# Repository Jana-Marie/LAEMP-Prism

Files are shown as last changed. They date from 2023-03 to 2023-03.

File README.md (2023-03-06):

# LAEMP-Prism

The LÄMP-Prism is an aesthetically pleasing and colorful effect lamp that can be used in your home. It can be controlled using Zigbee (e.g., Philips Hue) and has RGBY + WW/CW LEDs, providing a wide dynamic range and fantastic color representation. The lamp can be soldered together at home or assembled by JLCPCB.

An inbuilt slow fade-animation creates plenty colored dots around the room, one can choose from three different animations by quickly bringing red from 0% to 100% and back three times. LAEMP will switch from static light, to slow-fading dots to being an RGB-beacon. Its most pleasing mode is the slow-fading animation. It is fast enough to raise the rooms texture, slow enough to not be irritating and just perfect for comfy nights.

The project consists of nine PCBs that are cleverly interlocked with pinheaders and capacitors. The Prism-like shape, combined with its 291 LEDs, projects a slightly changing dotted pattern into its environment.

<table>
  <tbody>
    <tr>
      <td>
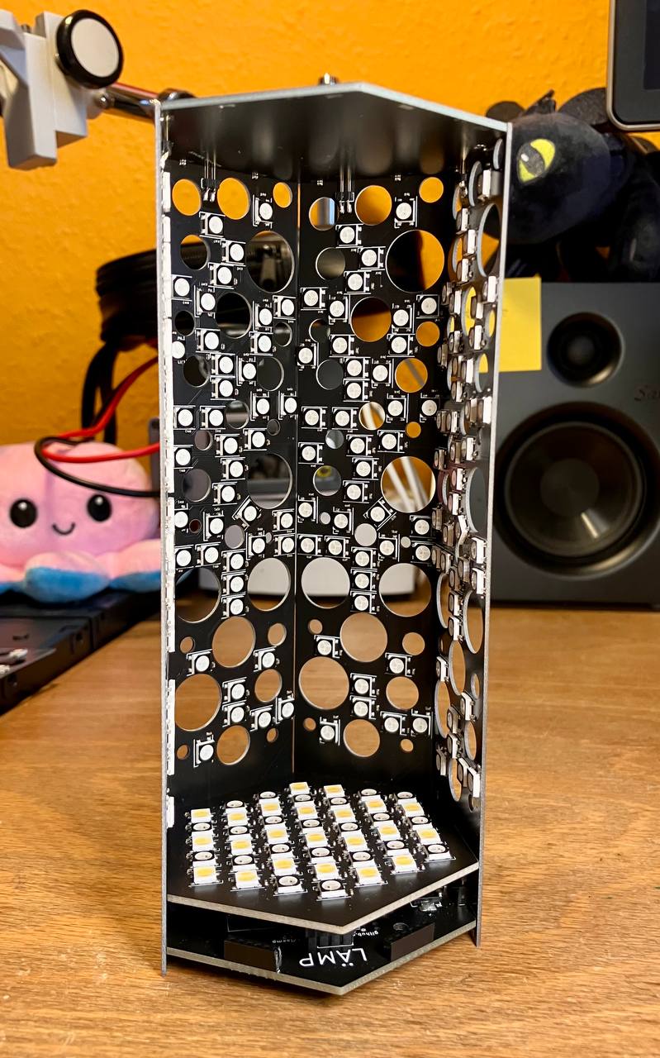
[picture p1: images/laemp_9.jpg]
        
      </td>
      <td>
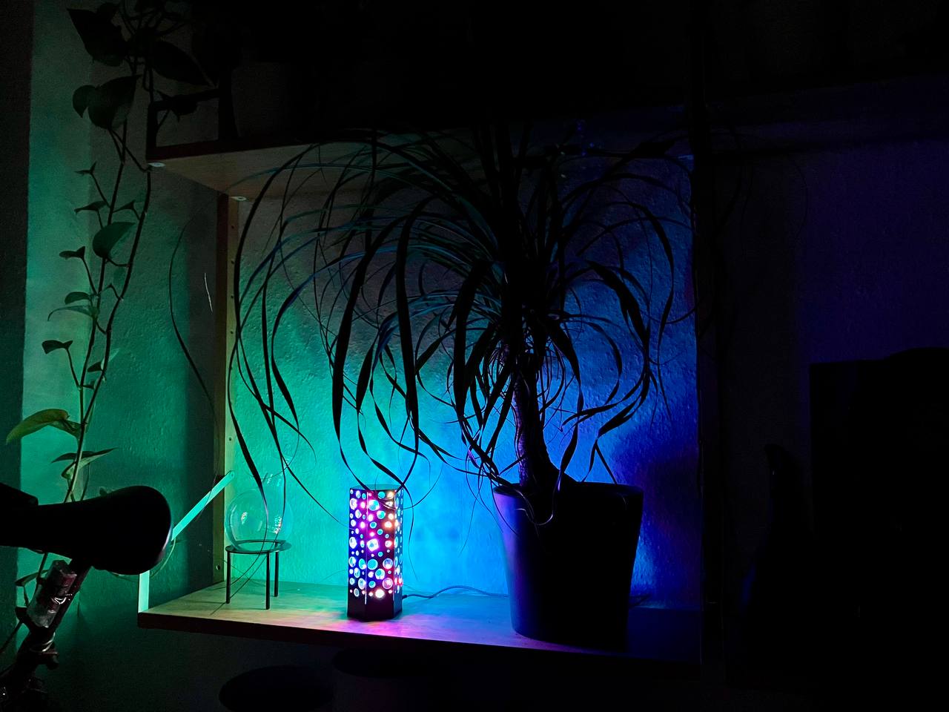
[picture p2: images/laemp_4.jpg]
        
      </td>
    </tr>
  </tbody>
</table>

This project is an attempt to add some colored lights and interesting patterns to ones home. I hope you enjoy it! :3

<table>
  <tbody>
    <tr>
      <td>
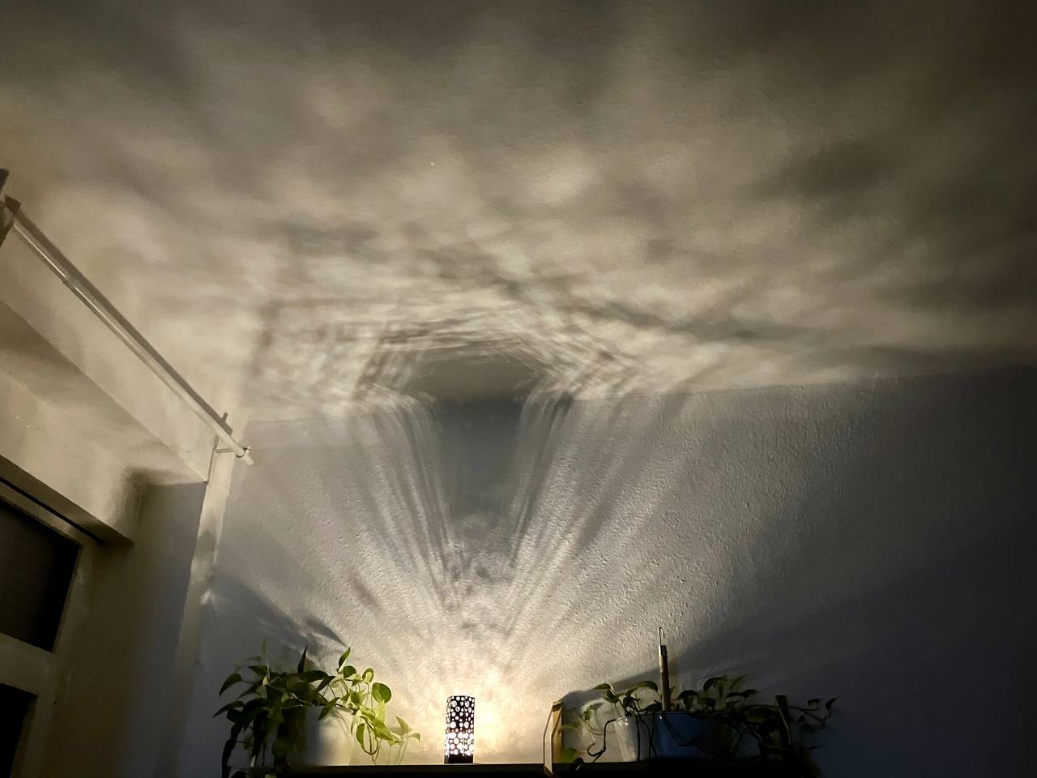
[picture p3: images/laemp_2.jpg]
        
      </td>
      <td>
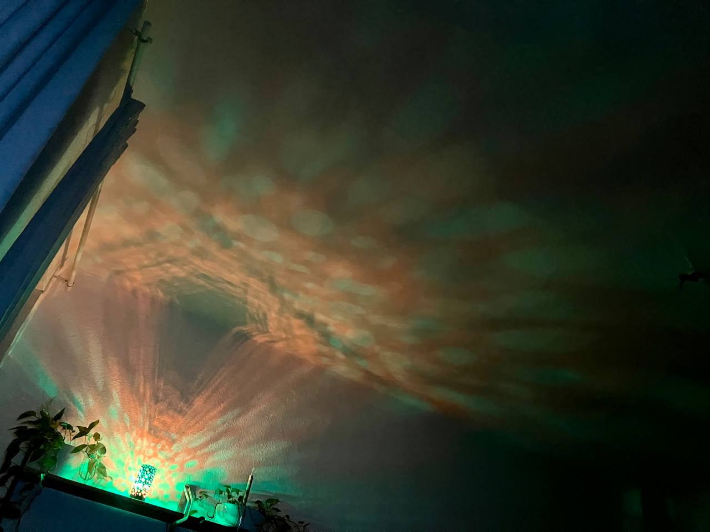
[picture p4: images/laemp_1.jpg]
        
      </td>
    </tr>
  </tbody>
</table>

### V2

Please note that the E75-2G4M20S module is End of Life and is hard to obtain. I'm working on a V2.0 with STM32WB (see [MiniBee](https://github.com/Jana-Marie/MiniBee)). The Hex-Base-Board is henceforth subject to be updated, all other boards shouldnt change.

### Sister project

LAEMP-Prism is a sister project to [LAEMP-Panel](https://github.com/Jana-Marie/LAEMP-Panel)

## Concept

The overall concept was developed in OpenSCAD and a pseudo-random pattern of circles was choosen for the walls. If one wants to put effort into this project, different walls can be used. The standard base-to-wall-interface also allows for much different and custom walls. E.g. hexagonal holes, shorter or taller walls, bended walls, ...

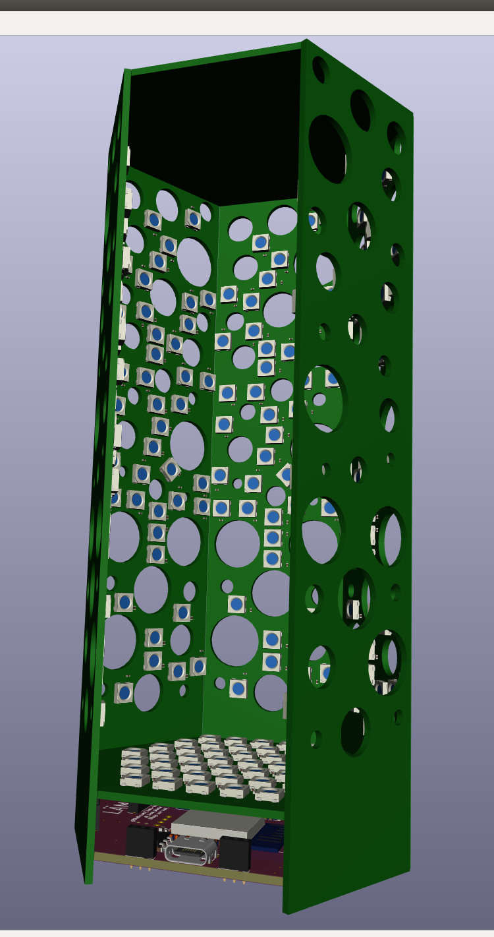
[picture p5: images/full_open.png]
full open


## Build

This build is definitely time-consuming, as each LAEMP Prism features 291 LEDs, and therefore requires at least 291 100nF capacitors. Additionally, the wall PCBs are rather thin and long, making reflow difficult and assembly time-consuming.

Once all eight boards are assembled (the top board has no components ^⁻^), they can be interlocked with one another. To do this, begin by plugging the LED-Base-Board into the Base-Board, and then carefully plugging wall after wall into the baseboard. Try to put the Top-Board onto the build after assembling five boards. The board with the Type-C cutout should not be the last board to assemble. Finally, try to plug in the last board. This step can be quite tricky and may require a few attempts. Once all boards are assembled, align all walls with each other and place the whole board onto the 3D printed base.

You will need the following set of baords for a build:

 - 1 x Base-Board
 - 1 x Base-LED-Board
 - 1 x Top-Board
 - 5 x Wall-Board
 - 1 x USB-Wall-Board

<table>
  <tbody>
    <tr>
      <td>
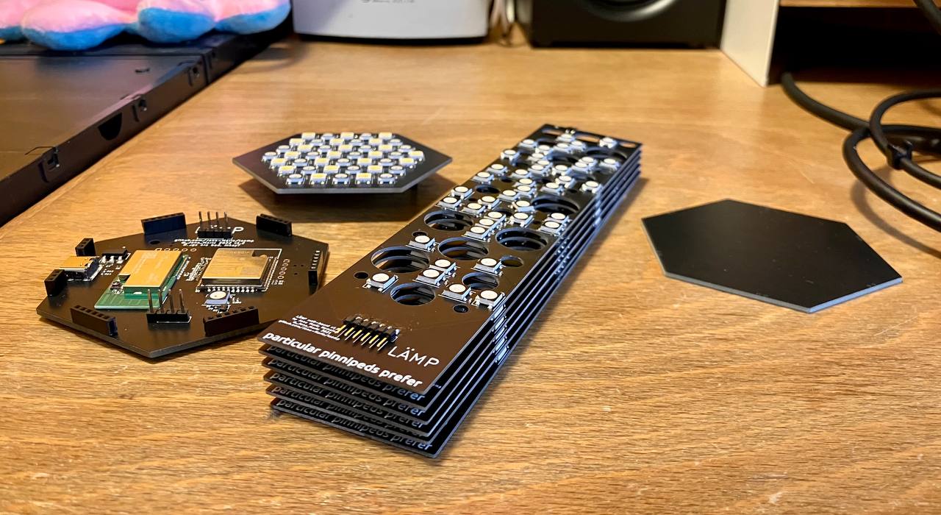
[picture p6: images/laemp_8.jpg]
        
      </td>
      <td>
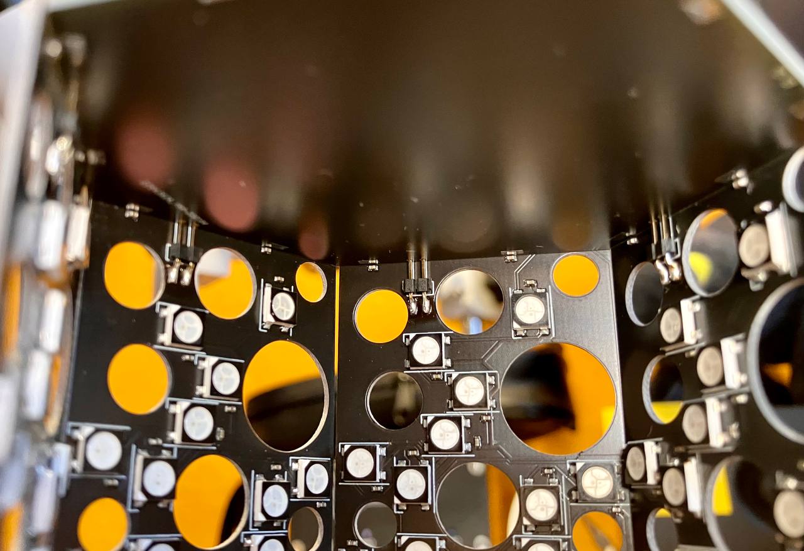
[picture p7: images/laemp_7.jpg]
        
      </td>
    </tr>
    <tr>
      <td>
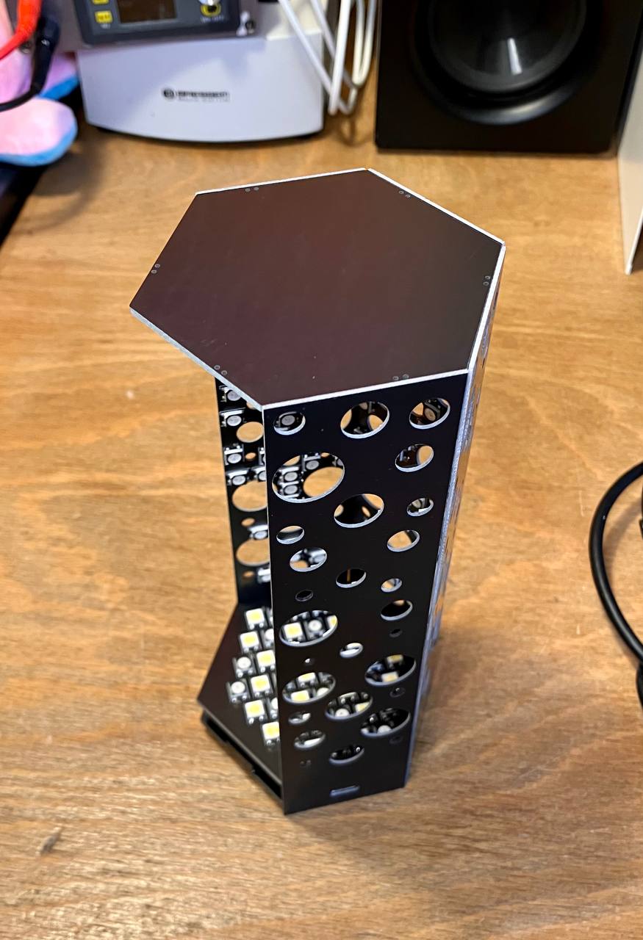
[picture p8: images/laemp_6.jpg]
        
      </td>
      <td>
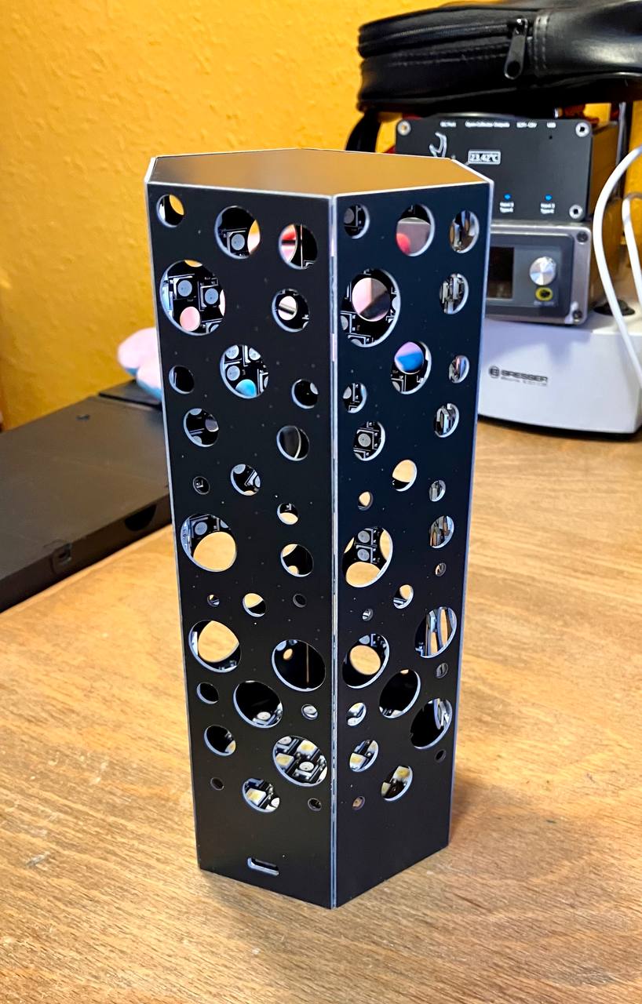
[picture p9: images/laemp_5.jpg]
        
      </td>
    </tr>
  </tbody>
</table>

## Firmware

There are two firmwares to be flashed, one for the ESP32 and one for the E75-2G4M20S.

### ESP32

This is a simple Arduino project and can be flashed via Arduino (initially built on Arduino 1.8.19).

### E75

Please refer to the awesome works of [PeeVeeOne](https://peeveeone.com/zll-tldr/) to flash `Light_ColorLight_JN5168_RGB` onto the E75-2G4M20S module.

## Todo

 - [ ] Bug: Animation selector sucks, it gets stuck on states, needs fix.
 - [ ] Bug: Color wheel is off
 - [ ] Update to baseboard v2

## Folder Structure

```
 - 3D/               3D-Printable base, Concept
 - design/           assets, renders
 - images/           images for README
 - laemp_base/       base board hosting the MCU(s)
 - laemp_led_board/  LED base board, plugs directly ontop of the base board
 - laemp_top/        top board, has no electrical functionality, just mechanical
 - laemp_wall/       wall board, hosting 41 leds each
 - laemp_wall_usb/   same wall board, but with USB cutout
 - firmware/
   - leamp_prism/    ESP32 FW
   - zigbee/         E75 FW
```

## License

Copyright Jana Marie Hemsing 2023.
This source describes Open Hardware and is licensed under the CERN-
OHL-S v2.

You may redistribute and modify this source and make products using it
under the terms of the CERN-OHL-S v2
([LICENSE](/LICENSE)).

This source is distributed WITHOUT ANY EXPRESS OR IMPLIED
WARRANTY, INCLUDING OF MERCHANTABILITY, SATISFACTORY
QUALITY AND FITNESS FOR A PARTICULAR PURPOSE. Please see
the CERN-OHL-S v2 for applicable conditions.

Source location: https://github.com/Jana-Marie/LAEMP-Prism/
As per CERN-OHL-S v2 section 4, should You produce hardware based
on this source, You must where practicable maintain the Source Location
visible on the external case of LAEMP-Prism or other products you make using
this source

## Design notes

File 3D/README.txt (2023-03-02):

# Structure

```
 ./laemp.scad
   Project file
 ./laemp_base.scad
   3D printable project base
 ./laemp_base.stl
   Print me!
 ./laemp_wall_1.dxf
   KiCAD outline file
```

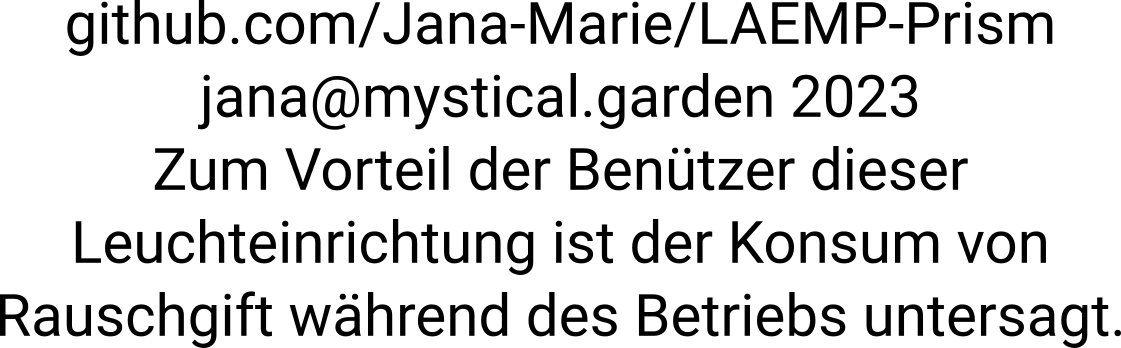
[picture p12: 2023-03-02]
design/bottom_text.png

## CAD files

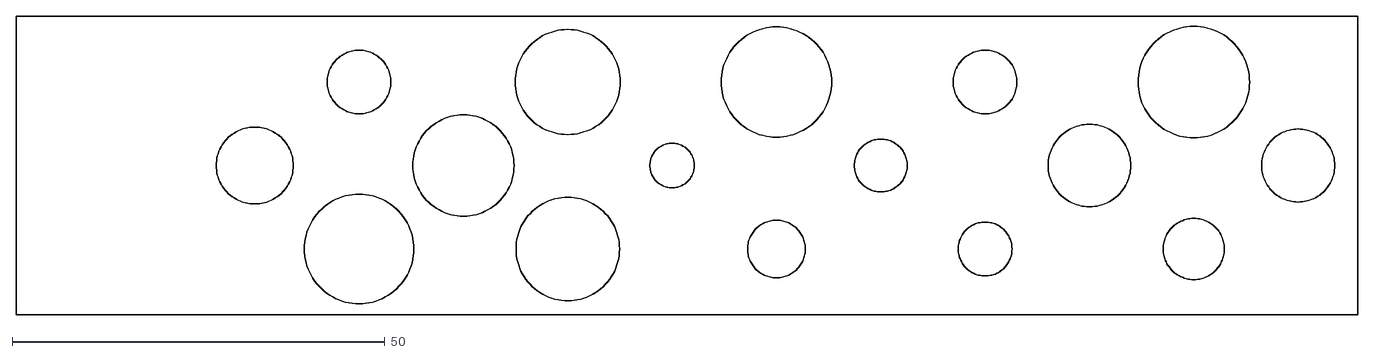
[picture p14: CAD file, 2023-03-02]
3D/laemp_wall_1.dxf
180.0 x 40.0

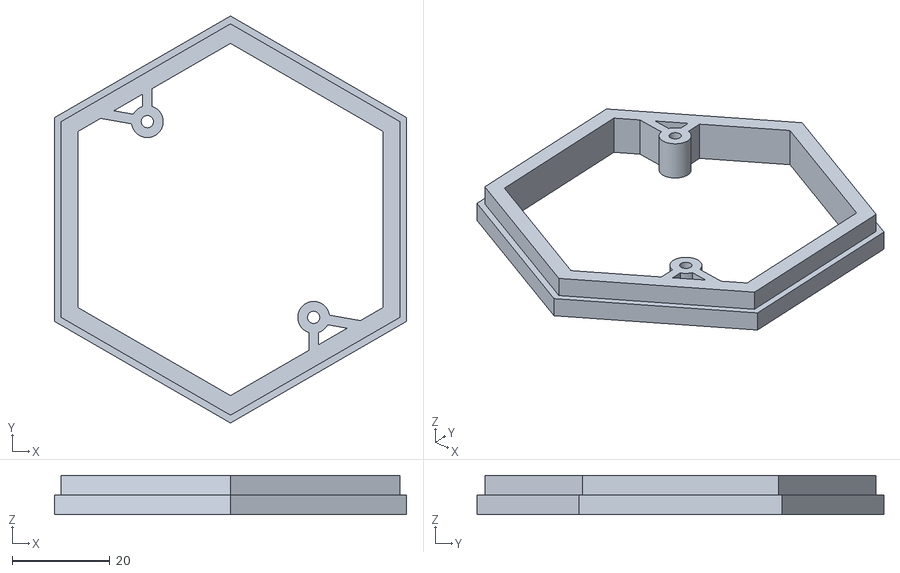
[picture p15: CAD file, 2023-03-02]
3D/laemp_base.stl
72.1 x 83.2 x 8.00

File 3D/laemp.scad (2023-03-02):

$fn = 100;
sidelenth=40;
height=180;

#color("darkgrey")
for(r=[0:60:300])rotate([0,0,r])translate([sidelenth*sqrt(3)/2+0.5,0,0])rotate([0,-90,0])wall_1(height,sidelenth);

//wall_1(height,sidelenth);

color("grey")translate([0,0,height])hexagon(sidelenth,true);

color("grey")translate([0,0,10])hexagon(sidelenth,true);

color("grey")translate([0,0,20])hexagon(sidelenth,true);

module wall_1(h=100,l=40,t=0.8){
    difference(){
        union(){
            translate([h/2,0,0])square([h,l],center=true);
        } union(){
            _xoff=32;
            _xdiff=28;
            for(i = [0:1:10]){
                for(k = [-1:1:1]){
                    _d = rands(3,15,1)[0];
                    //ssecho(_d,k%2==0 ? _xoff+(i*_xdiff):_xoff+((i*_xdiff)+(_xdiff/2)),(k*_xdiff/2.5));
                    translate([k%2==0 ? _xoff+(i*_xdiff):_xoff+((i*_xdiff)+(_xdiff/2)),(k*_xdiff/2.5),0])
                        
                        circle(d=_d);
                }
            }
        }
    }
}

module hexagon(s, center=false){
    l = sqrt(3) * s;
    tr = center ? [0, 0, 0] : [s, l / 2, 0];
    translate(tr)for(r =[-60,0,60])rotate([0,0,r])square([l,s],center=true);
}

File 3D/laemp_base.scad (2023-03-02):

$fn=100;

color([0, 49/255, 83/255])laemp_base(4, 4, false);

module laemp_base(h=10, h_lower=5, thread=false){
    union(){
        // upper hexagon
        difference(){
            rotate([0,0,90])hexagon(40,h);
            translate([0,0,-0.5])rotate([0,0,90])hexagon(36,h+1);
        }
        // lower hexagon
        translate([0,0, -h_lower])
        difference(){
            rotate([0,0,90])hexagon(40+1.6,h_lower);
            translate([0,0,-0.5])rotate([0,0,90])hexagon(36,h_lower+1);
        }
        // screwholes
        translate([-17,20,-h_lower])mounting_holes(2.5,h+h_lower,2);
        translate([17,-20,-h_lower])mounting_holes(2.5,h+h_lower,2);
        // bridges
        translate([-17,20,h/2-h_lower/2]){
            rotate([0,0,90])translate([3+2,0,0])cube([6,2,h+h_lower],center=true);
            rotate([0,0,170])translate([5+2,0,0])cube([10,2,h+h_lower],center=true);
        }
        translate([17,-20,h/2-h_lower/2]){
            rotate([0,0,-90])translate([3+2,0,0])cube([6,2,h+h_lower],center=true);
            rotate([0,0,-10])translate([5+2,0,0])cube([10,2,h+h_lower],center=true);
        }
    }
}

module thread(do=10,di=9,s=1.9,h=10,res=5){
    ssize=360/res;
    for(i=[1:res:360/s*h]){
        rotate([0,0,i])translate([(do-di)/2,0,s*i/360-0.01])cylinder(h=s/ssize+0.02,d=di);
    }
}

module mounting_holes(sDia=3,h=1,wall=2){
    difference(){
        cylinder(d=wall*2+sDia,h=h);
        translate([0,0,-0.5])cylinder(d=sDia,h=h+1);
    }
}

module hexagon(x = 10, h = 1){
    cylinder(d=x*2, h=h, $fn=6);
}

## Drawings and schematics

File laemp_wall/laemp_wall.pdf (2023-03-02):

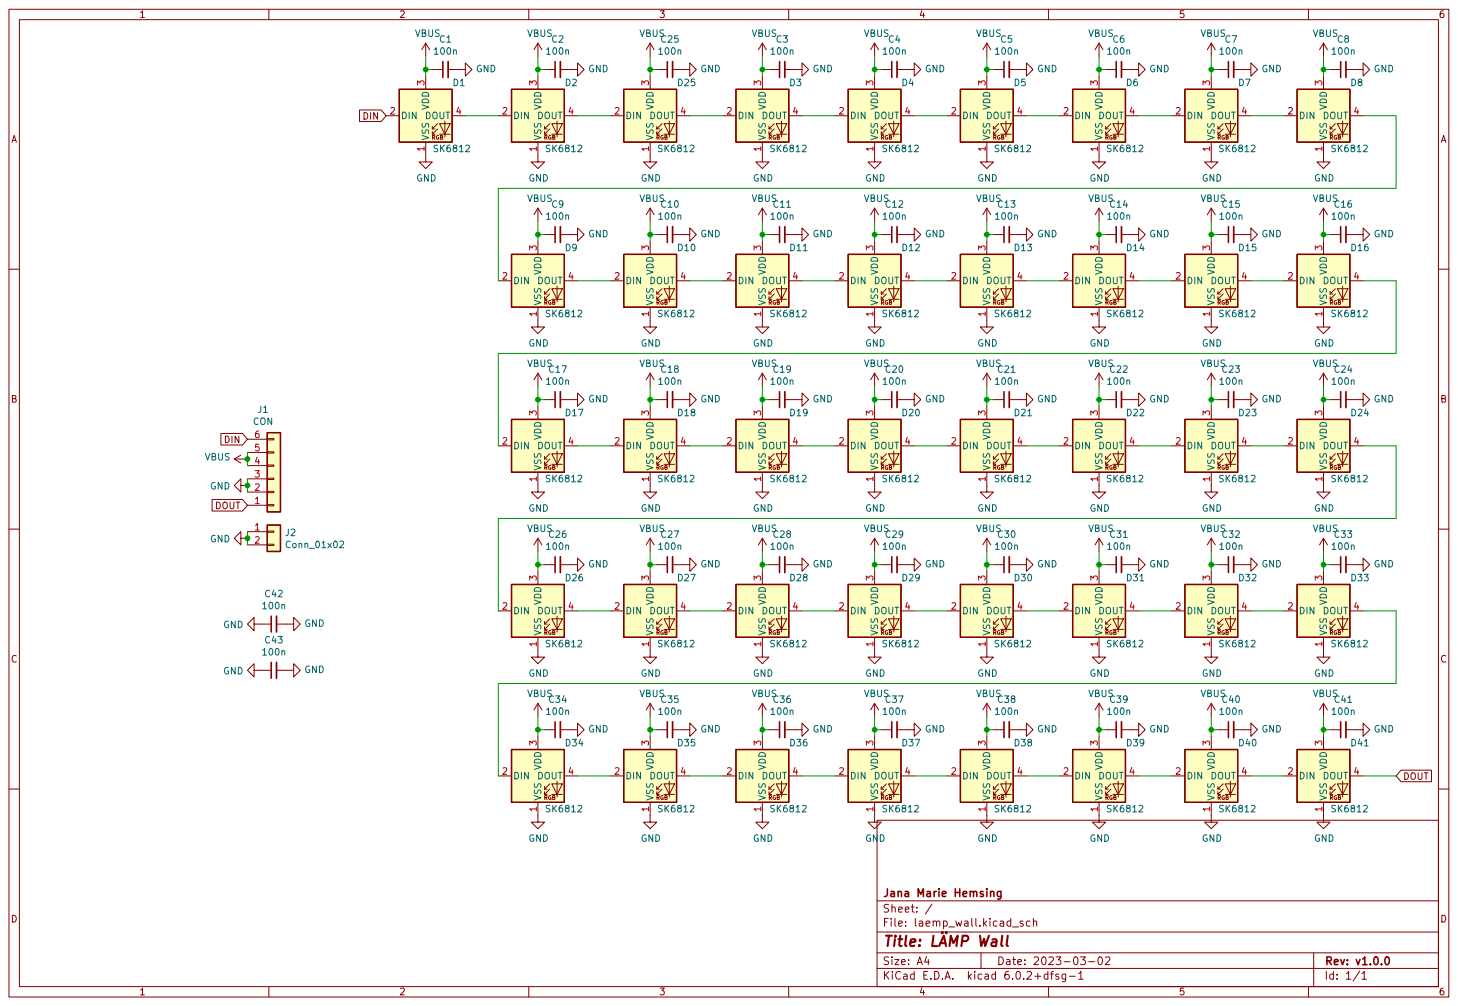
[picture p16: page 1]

3 DOUT 4D6 SK6812 VSS RGB 1 DIN 2 VDD

3 DOUT 4D23 SK6812 VSS RGB 1 DIN 2 VDD

3 DOUT 4D10 SK6812 VSS RGB 1 DIN 2 VDD

3 DOUT 4D11 SK6812 GNDVSS RGB 1 DIN 2 VDD

3 DOUT 4D13 SK6812 GND VSS RGB 1 DIN 2 VDD

3 DOUT 4D15 SK6812 GND GNDVSS RGB 1 DIN 2 VDD

3 DOUT 4D24 SK6812 VSS RGB 1 DIN 2 VDD

3 DOUT 4D40 SK6812 GND GNDVSS RGB 1 DIN 2 VDD

3 DOUT 4D20 SK6812 GND VSS RGB 1 DIN 2 VDD

3 DOUT 4D33 SK6812 GND GND VSS RGB 1 DIN 2 VDD

3 DOUT 4D31 SK6812 VSS RGB 1 DIN 2 VDD

3 DOUT 4D30 SK6812 VSS RGB 1 DIN 2 VDD

3 DOUT 4D37 SK6812 GND GNDVSS RGB 1 DIN 2 VDD

File: laemp_wall.kicad_sch Sheet: / Jana Marie Hemsing GND

3 DOUT 4D38 SK6812 VSS RGB 1 DIN 2 VDD

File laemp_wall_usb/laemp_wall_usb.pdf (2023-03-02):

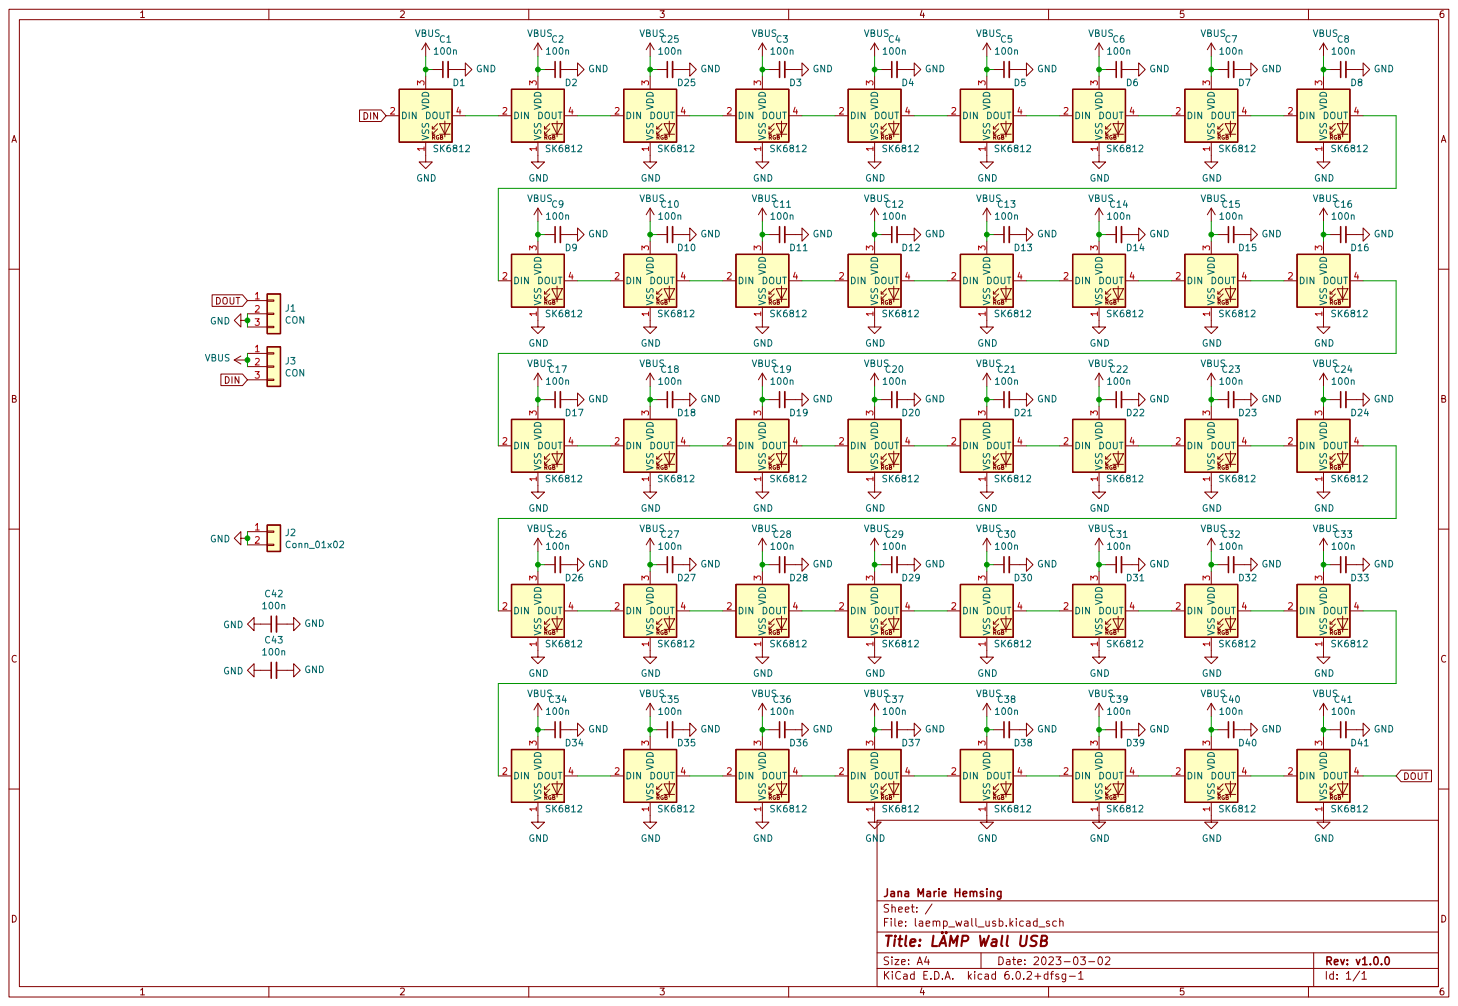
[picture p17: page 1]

3 DOUT 4D2 SK6812 VBUS GND GND

3 DOUT 4D8 SK6812 GND GND GND

3 DOUT 4D6 SK6812 VSS RGB 1 DIN 2 VDD

3 DOUT 4D20 SK6812 GND GND VSS RGB 1 DIN 2 VDD

3 DOUT 4D14 SK6812 GND GND GND GND VSS RGB 1 DIN 2 VDD

3 DOUT 4D12 SK6812 VSS RGB 1 DIN 2 VDD

3 DOUT 4D11 SK6812 VSS RGB 1 DIN 2 VDD

3 DOUT 4D10 SK6812 VSS RGB 1 DIN 2 VDD

3 DOUT 4D13 SK6812 VSS RGB 1 DIN 2 VDD

3 DOUT 4D23 SK6812 VSS RGB 1 DIN 2 VDD

3 DOUT 4D26 SK6812 GND GND VSS RGB 1 DIN 2 VDD

3 DOUT 4D29 SK6812 GNDVSS RGB 1 DIN 2 VDD

3 DOUT 4D27 SK6812 GND VSS RGB 1 DIN 2 VDD

3 DOUT 4D31 SK6812 GNDVSS RGB 1 DIN 2 VDD

3 DOUT 4D37 SK6812 VSS RGB 1 DIN 2 VDD

3 DOUT 4D41 SK6812 GND VSS RGB 1 DIN 2 VDD

3 DOUT 4D34 SK6812 GND GNDVSS RGB 1 DIN 2 VDD

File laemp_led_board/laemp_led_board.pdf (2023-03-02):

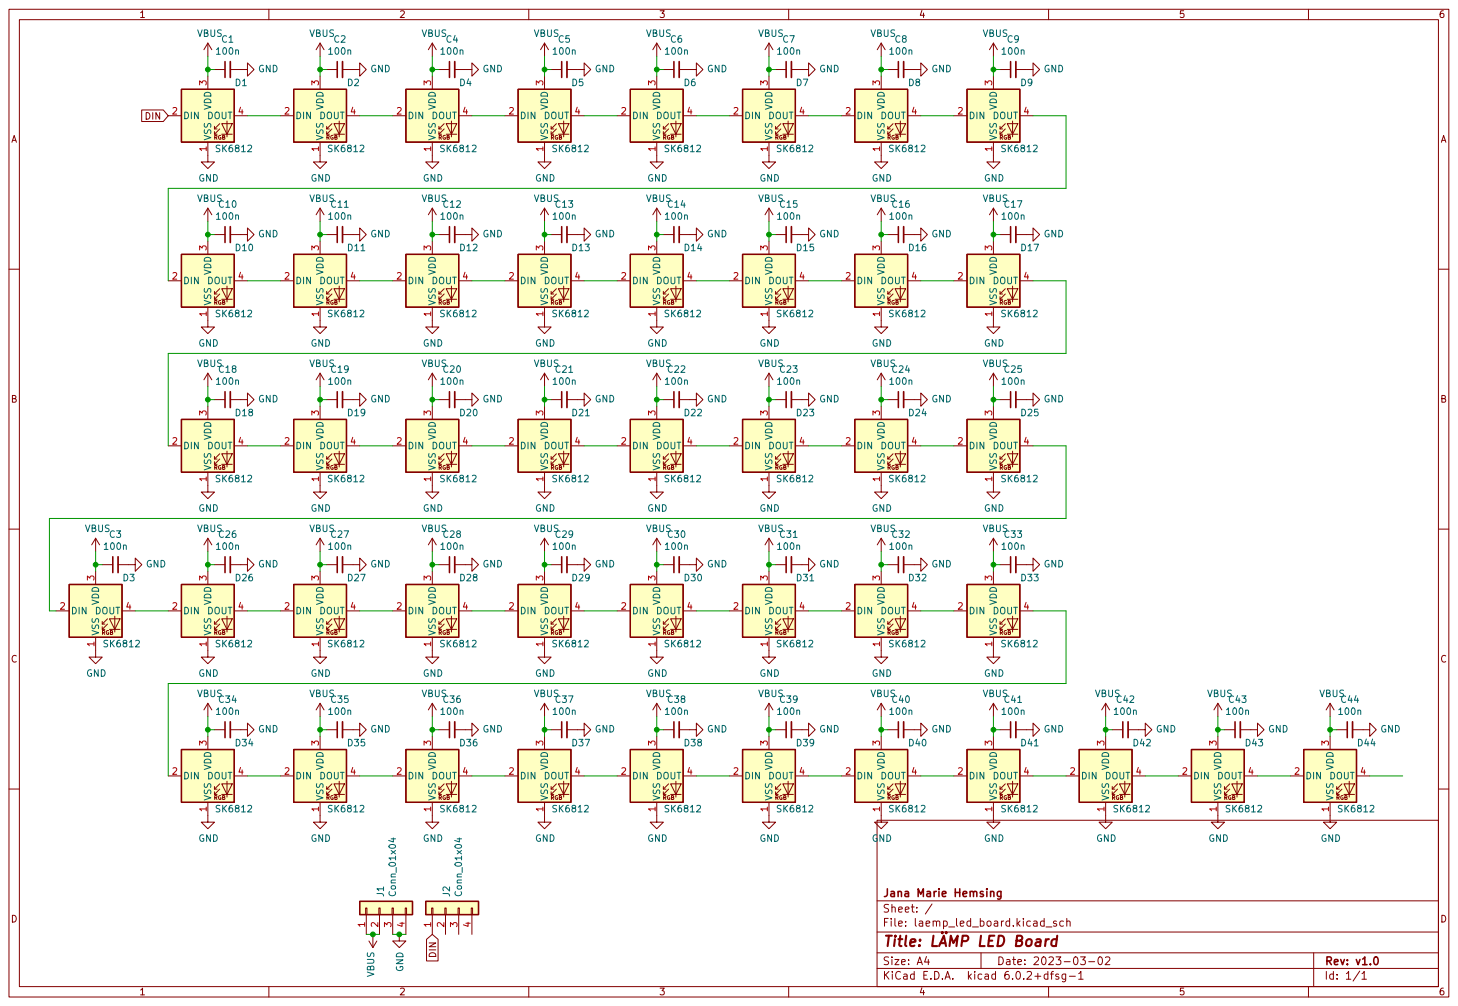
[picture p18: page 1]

3 DOUT 4D35 SK6812 GND GND GND GND VSS RGB 1 DIN 2 VDD

3 DOUT 4D6 SK6812 VBUS VSS RGB 1 DIN 2 VDD

3 DOUT 4D8 SK6812 GNDVSS RGB 1 DIN 2 VDD

3 DOUT 4D11 SK6812 VSS RGB 1 DIN 2 VDD

3 DOUT 4D27 SK6812 VSS RGB 1 DIN 2 VDD

3 DOUT 4D19 SK6812 GND VSS RGB 1 DIN 2 VDD

3 DOUT 4D14 SK6812 GND VSS RGB 1 DIN 2 VDD

3 DOUT 4D15 SK6812 VSS RGB 1 DIN 2 VDD

3 DOUT 4D13 SK6812 VSS RGB 1 DIN 2 VDD

3 DOUT 4D32 SK6812 VBUS GND VSS RGB 1 DIN 2 VDD

3 DOUT 4D25 SK6812 VBUS GND GND

3 DOUT 4D28 SK6812 VSS RGB 1 DIN 2 VDD

File: laemp_led_board.kicad_sch Sheet: / Jana Marie Hemsing

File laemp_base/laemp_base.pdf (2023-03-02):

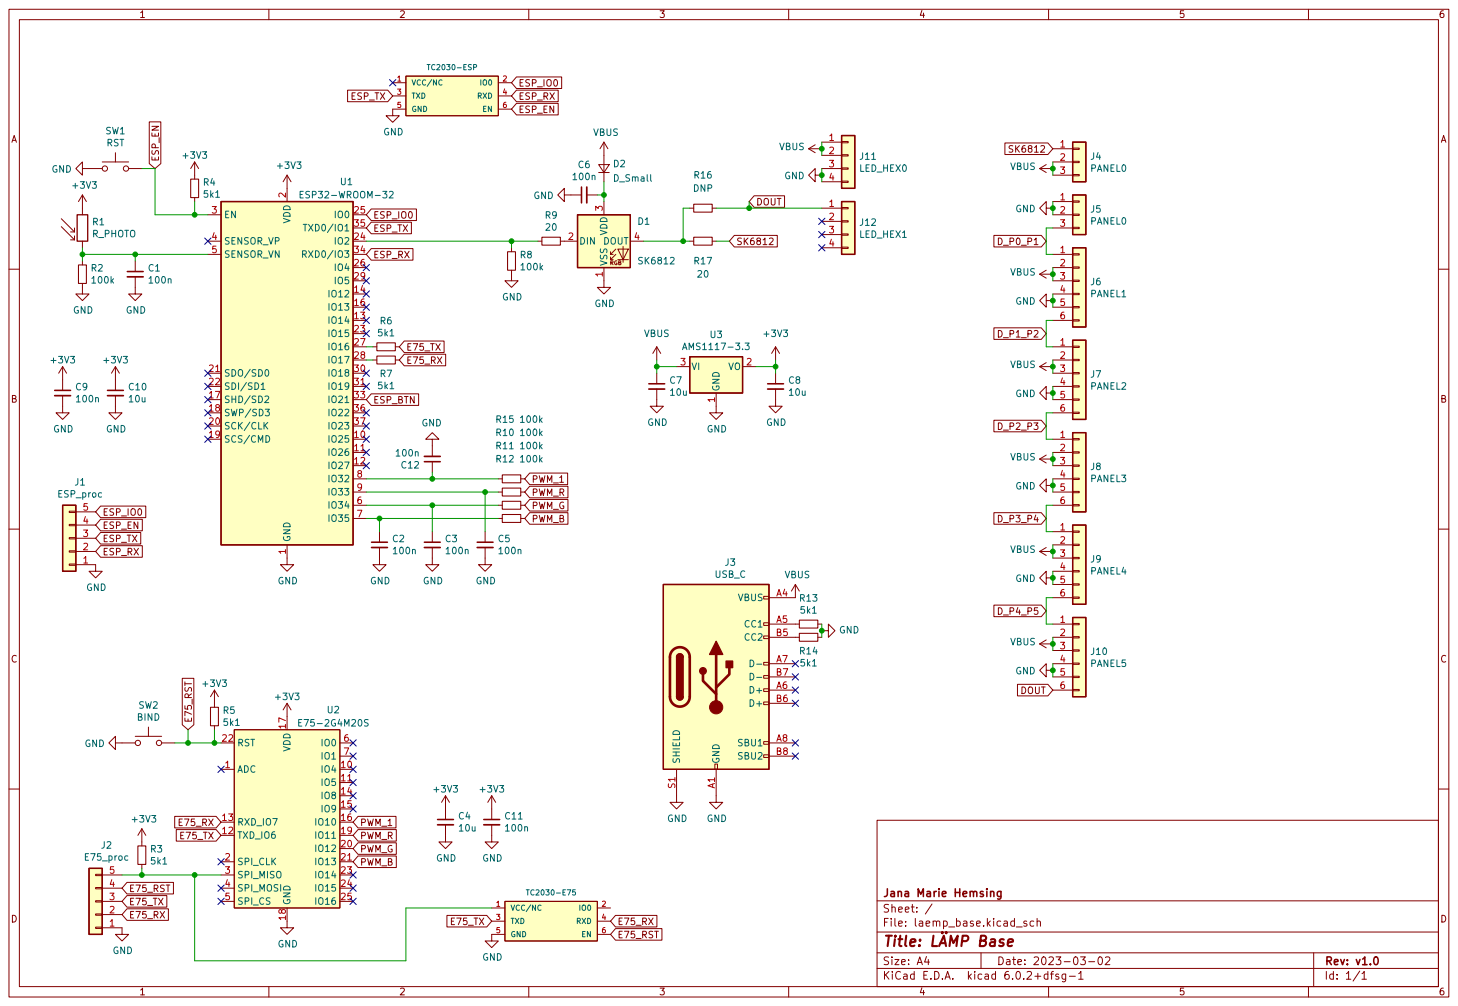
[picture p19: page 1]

File: laemp_base.kicad_sch Sheet: / Jana Marie Hemsing

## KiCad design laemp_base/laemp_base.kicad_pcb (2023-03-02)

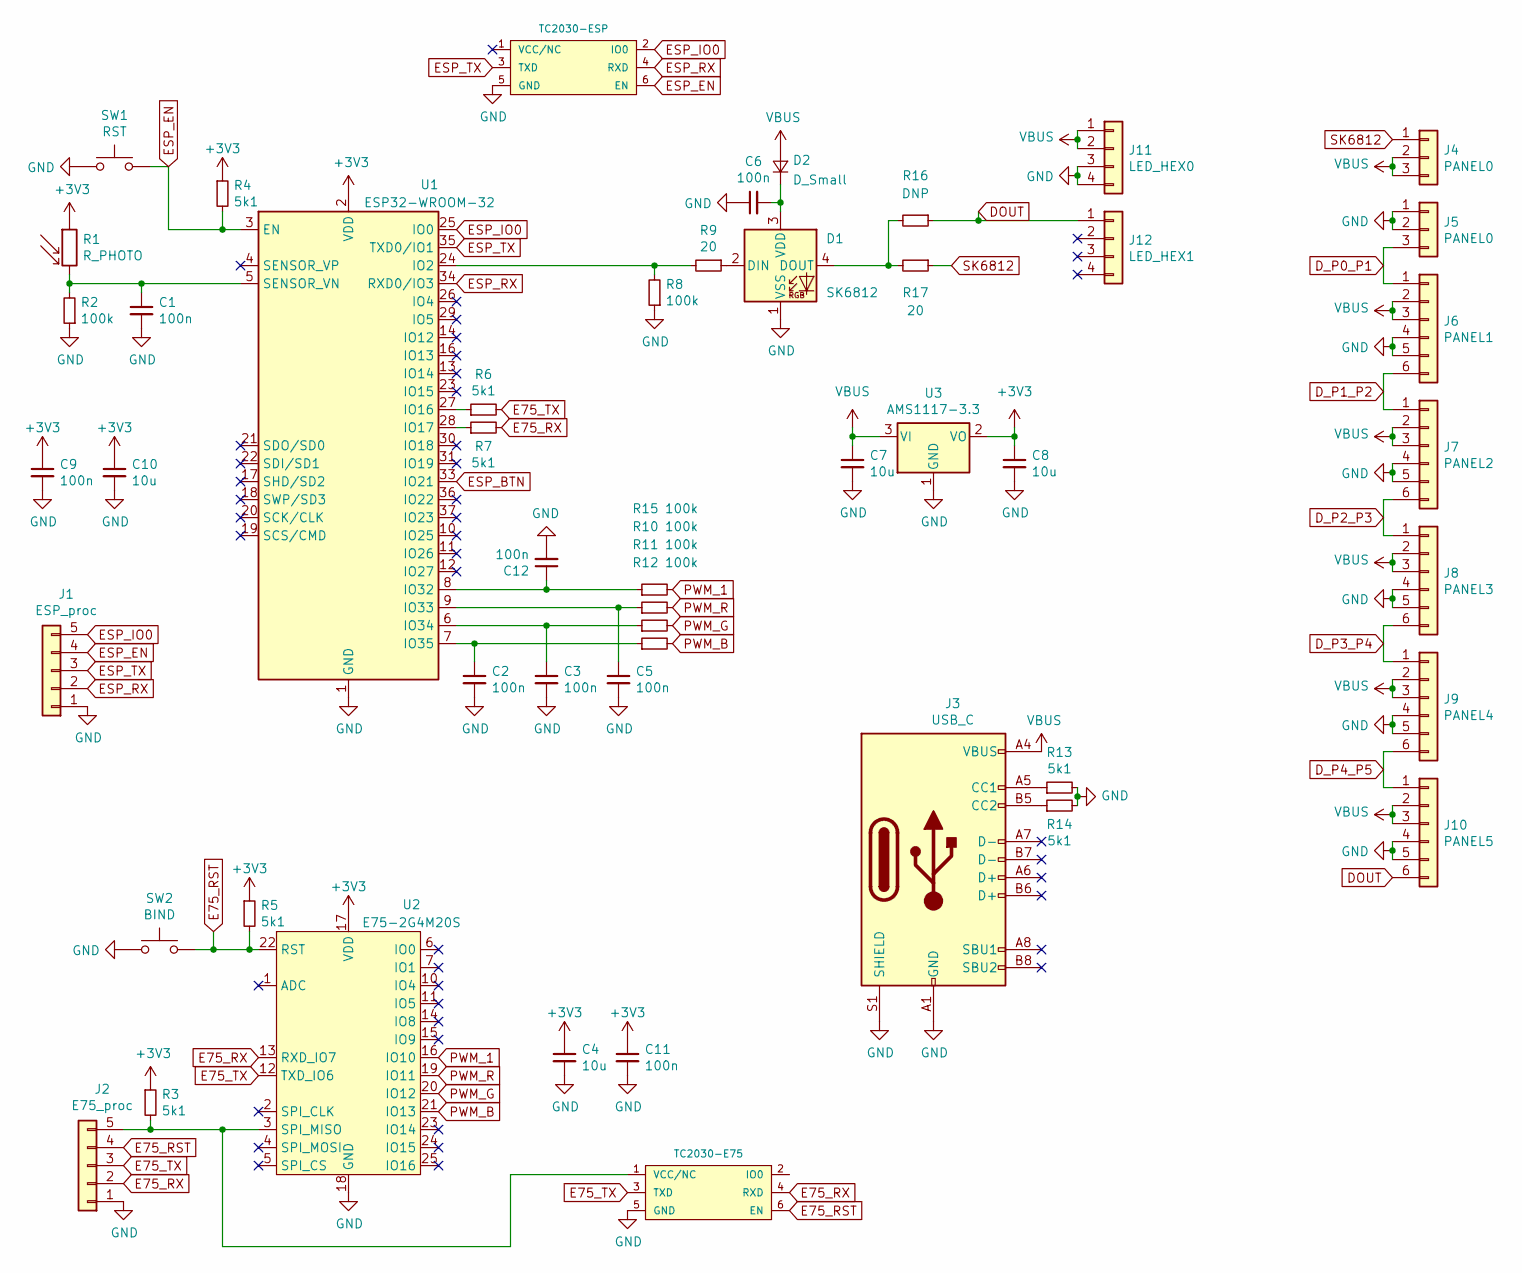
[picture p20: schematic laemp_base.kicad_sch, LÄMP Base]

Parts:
C1, C2, C3, C5, C6, C9, C11, C12: 100n; C_0402
C4, C7, C8, C10: 10u; C_0603
D1: SK6812; LED_SK6812_PLCC4_5.0x5.0mm_P3.2mm
D2: D_Small; D_SOD-123F
J1: ESP_proc; PinHeader_1x05_P2.54mm_Vertical
J2: E75_proc; PinHeader_1x05_P2.54mm_Vertical
J3: USB_C; USB-C 16Pin
J4, J5: PANEL0; PinSocket_1x03_P2.00mm_Vertical
J6: PANEL1; PinSocket_1x06_P2.00mm_Vertical_center
J7: PANEL2; PinSocket_1x06_P2.00mm_Vertical_center
J8: PANEL3; PinSocket_1x06_P2.00mm_Vertical_center
J9: PANEL4; PinSocket_1x06_P2.00mm_Vertical_center
J10: PANEL5; PinSocket_1x06_P2.00mm_Vertical_center
J11: LED_HEX0; PinSocket_1x04_P2.54mm_Vertical_center
J12: LED_HEX1; PinSocket_1x04_P2.54mm_Vertical_center
P1: TC2030-ESP; TC2030
P2: TC2030-E75; TC2030
R1: R_PHOTO; R_0805
R2, R8, R10, R11, R12, R15: 100k; R_0402
R3, R4, R5, R6, R7, R13, R14: 5k1; R_0402
R9, R17: 20; R_0402
R16: DNP; R_0402
SW1: RST; SW_SPST_PTS810
SW2: BIND; SW_SPST_PTS810
U1: ESP32-WROOM-32
U2: E75-2G4M20S; E75-2G4M10S
U3: AMS1117-3.3; SOT-223-3_TabPin2

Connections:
+3V3: C4.1, C8.1, C9.1, C10.1, C11.1, R1.1, R3.1, R4.1, R5.1, U1.2 (VDD), U2.17 (VDD), U3.2 (VO)
DOUT: J10.6, J12.1, R16.1
D_P0_P1: J5.3, J6.1
D_P1_P2: J6.6, J7.1
D_P2_P3: J7.6, J8.1
D_P3_P4: J8.6, J9.1
D_P4_P5: J9.6, J10.1
E75_RST: J2.4, P2.6 (EN), R5.2, SW2.2, U2.22 (RST)
E75_RX: J2.2, P2.4 (RXD), R7.2, U2.13 (RXD_IO7)
E75_TX: J2.3, P2.3 (TXD), R6.2, U2.12 (TXD_IO6)
ESP_BTN: U1.33 (IO21)
ESP_EN: J1.4, P1.6 (EN), R4.2, SW1.2, U1.3 (EN)
ESP_IO0: J1.5, P1.2 (IO0), U1.25 (IO0)
ESP_RX: J1.2, P1.4 (RXD), U1.34 (RXD0/IO3)
ESP_TX: J1.3, P1.3 (TXD), U1.35 (TXD0/IO1)
GND: C1.2, C2.2, C3.2, C4.2, C5.2, C6.1, C7.2, C8.2, C9.2, C10.2, C11.2, C12.2, D1.1 (VSS), J1.1, J2.1, J3.A1 (GND), J3.A12 (GND), J3.B1 (GND), J3.B12 (GND), J3.S1 (SHIELD), J5.1, J5.2, J6.4, J6.5, J7.4, J7.5, J8.4, J8.5, J9.4, J9.5, J10.4, J10.5, J11.3, J11.4, P1.5 (GND), P2.5 (GND), R2.1, R8.1, R13.2, R14.2, SW1.1, SW2.1, U1.1 (GND), U1.15 (GND), U1.38 (GND), U1.39 (GND), U2.18 (GND), U3.1 (GND)
unnamed: C1.1, R1.2, R2.2, U1.5 (SENSOR_VN)
unnamed: C2.1, R12.1, U1.7 (IO35)
unnamed: C3.1, R11.1, U1.6 (IO34)
unnamed: C5.1, R10.1, U1.9 (IO33)
unnamed: C6.2, D1.3 (VDD), D2.1 (K)
unnamed: C12.1, R15.1, U1.8 (IO32)
unnamed: D1.2 (DIN), R9.1
unnamed: D1.4 (DOUT), R16.2, R17.2
unnamed: J2.5, P2.1 (VCC/NC), R3.2, U2.3 (SPI_MISO)
unnamed: J3.A5 (CC1), R13.1
unnamed: J3.B5 (CC2), R14.1
unnamed: R6.1, U1.27 (IO16)
unnamed: R7.1, U1.28 (IO17)
unnamed: R8.2, R9.2, U1.24 (IO2)
PWM_1: R15.2, U2.16 (IO10)
PWM_B: R12.2, U2.21 (IO13)
PWM_G: R11.2, U2.20 (IO12)
PWM_R: R10.2, U2.19 (IO11)
SK6812: J4.1, R17.1
VBUS: C7.1, D2.2 (A), J3.A4 (VBUS), J3.A9 (VBUS), J3.B4 (VBUS), J3.B9 (VBUS), J4.2, J4.3, J6.2, J6.3, J7.2, J7.3, J8.2, J8.3, J9.2, J9.3, J10.2, J10.3, J11.1, J11.2, U3.3 (VI)

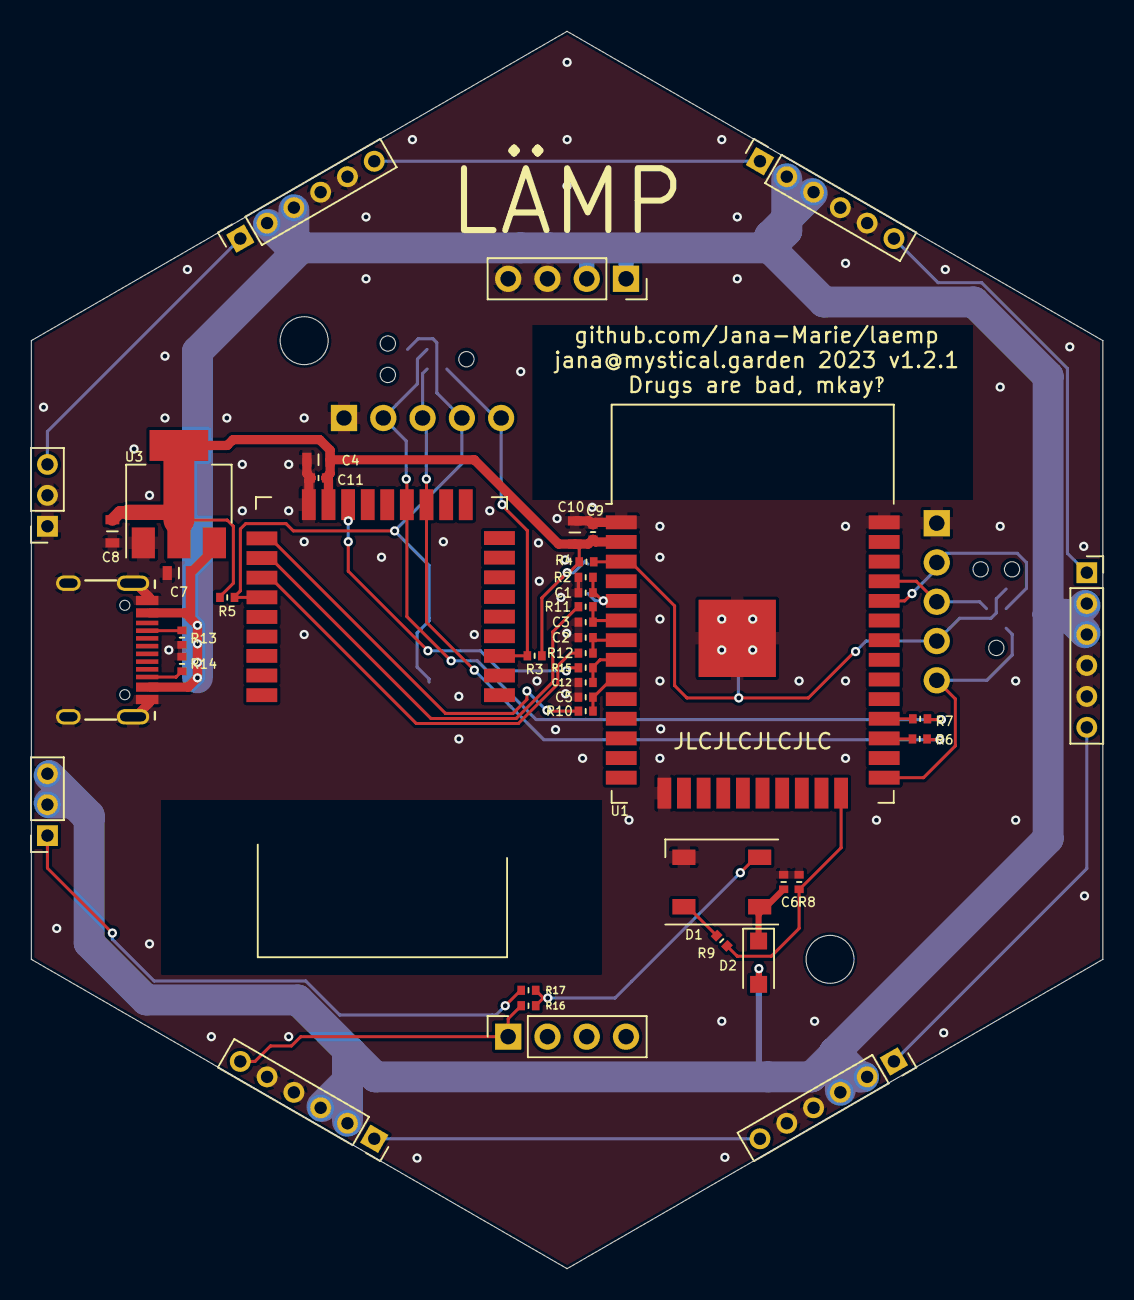
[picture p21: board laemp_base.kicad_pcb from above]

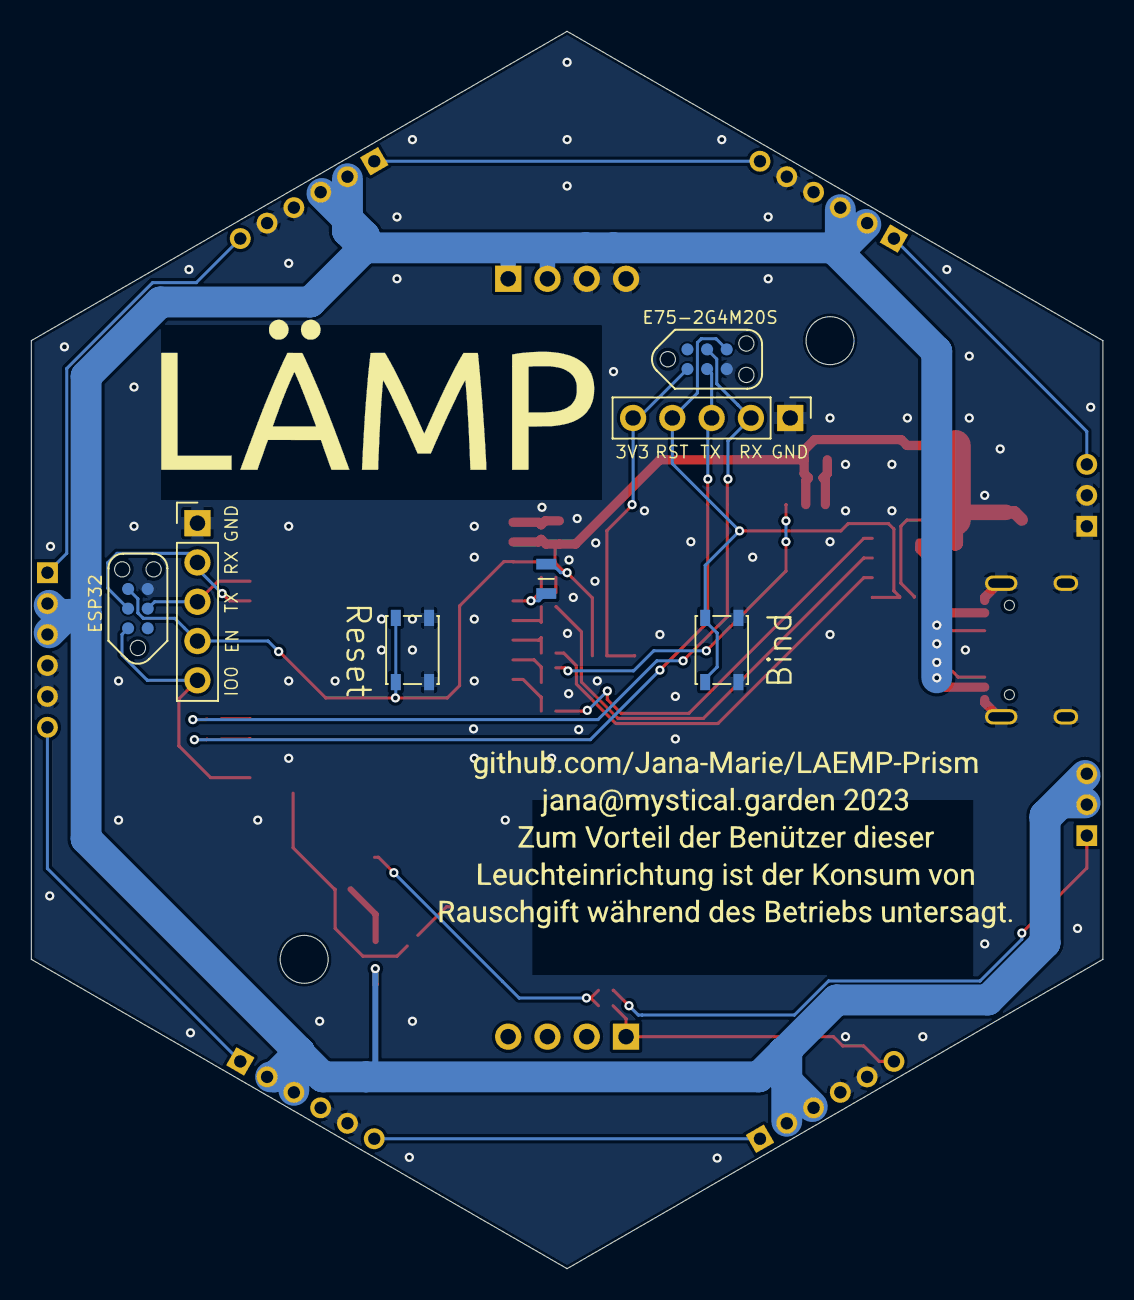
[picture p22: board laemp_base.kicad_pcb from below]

Board: 2 copper layers, 69.3 x 80.0 mm, 50 parts (7 on the bottom side), 35 nets.

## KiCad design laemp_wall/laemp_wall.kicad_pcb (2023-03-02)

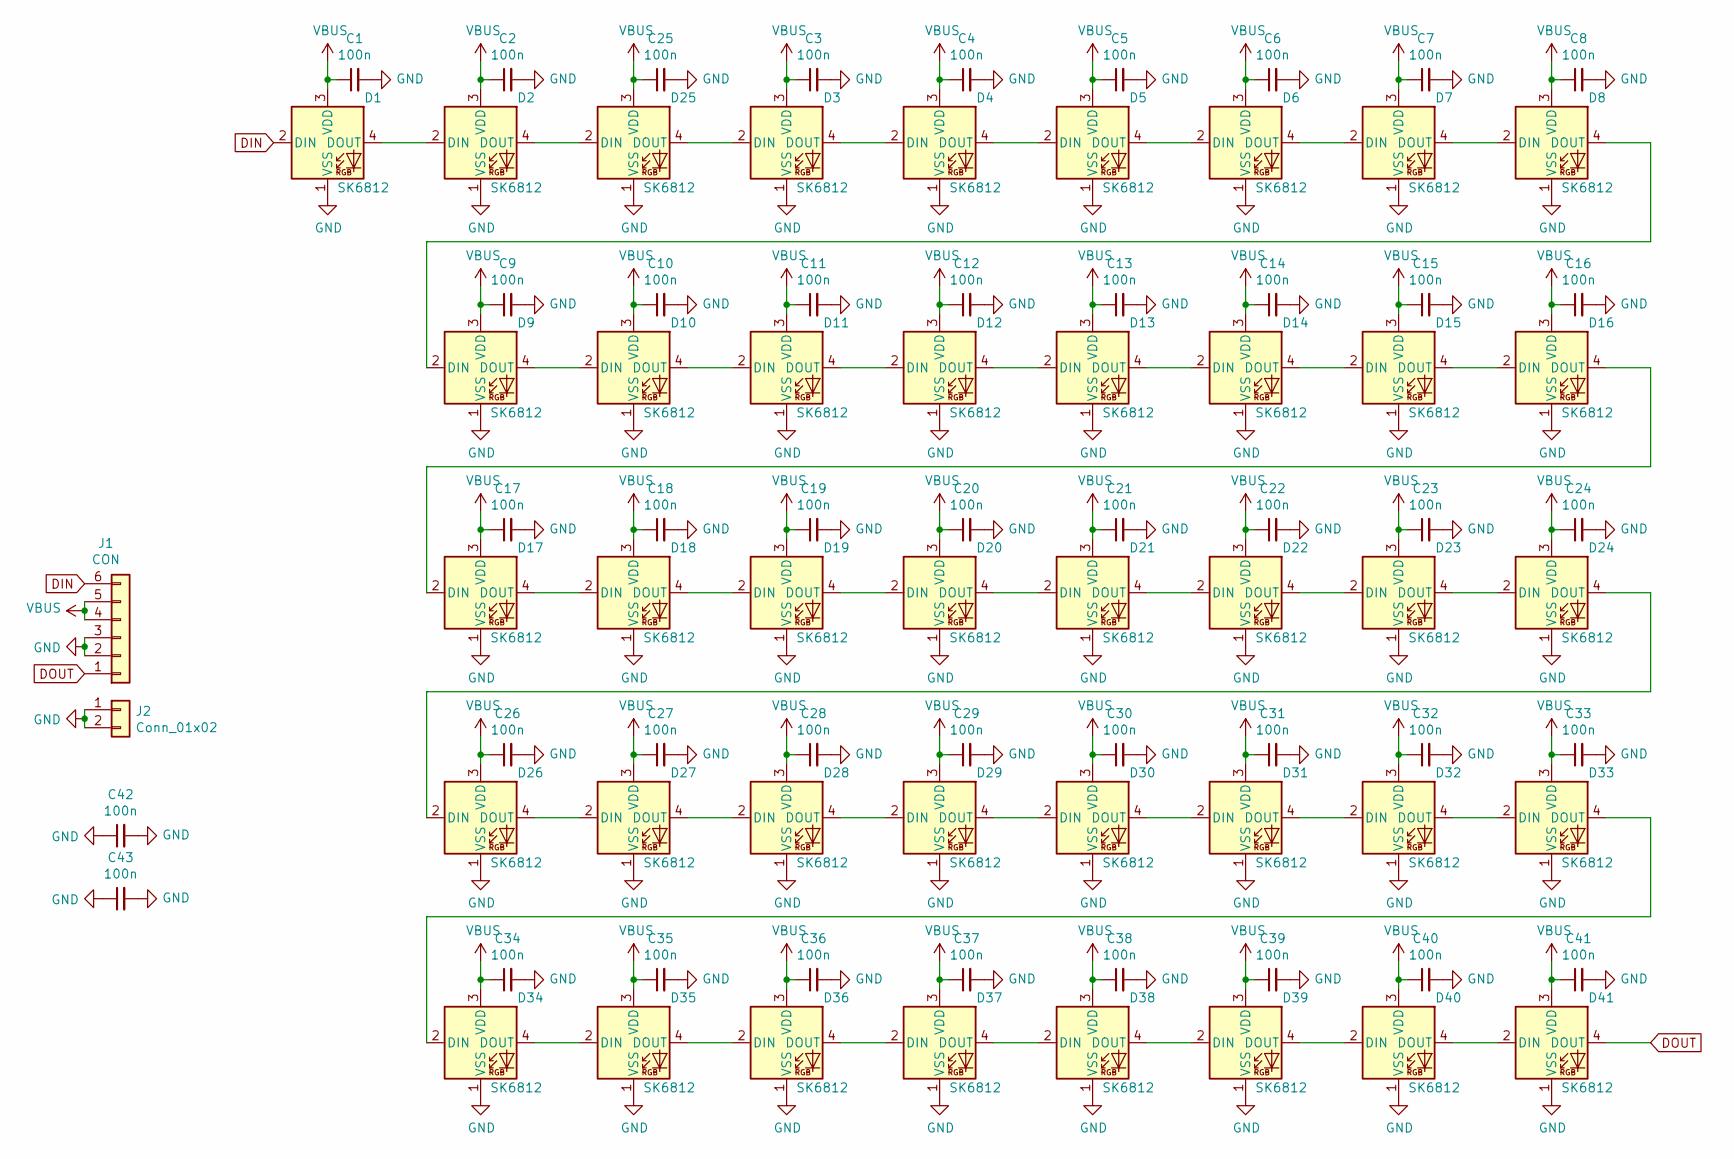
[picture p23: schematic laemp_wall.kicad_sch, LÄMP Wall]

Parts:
C1, C2, C3, C4, C5, C6, C7, C8, C9, C10, C11, C12, C13, C14, C15, C16, C17, C18, C19, C20, C21, C22, C23, C24, C25, C26, C27, C28, C29, C30, C31, C32, C33, C34, C35, C36, C37, C38, C39, C40, C41, C42, C43: 100n; C_0402
D1, D2, D3, D4, D5, D6, D7, D8, D9, D10, D11, D12, D13, D14, D15, D16, D17, D18, D19, D20, D21, D22, D23, D24, D25, D26, D27, D28, D29, D30, D31, D32, D33, D34, D35, D36, D37, D38, D39, D40, D41: SK6812; LED_SK6812_PLCC4_5.0x5.0mm_P3.2mm
J1: CON; conn_01x06_smd_2mm
J2: Conn_01x02; conn_01x02_smd_2mm

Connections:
DIN: D1.2 (DIN), J1.6
DOUT: D41.4 (DOUT), J1.1
GND: C1.2, C2.2, C3.2, C4.2, C5.2, C6.2, C7.2, C8.2, C9.2, C10.2, C11.2, C12.2, C13.2, C14.2, C15.2, C16.2, C17.2, C18.2, C19.2, C20.2, C21.2, C22.2, C23.2, C24.2, C25.2, C26.2, C27.2, C28.2, C29.2, C30.2, C31.2, C32.2, C33.2, C34.2, C35.2, C36.2, C37.2, C38.2, C39.2, C40.2, C41.2, C42.1, C42.2, C43.1, C43.2, D1.1 (VSS), D2.1 (VSS), D3.1 (VSS), D4.1 (VSS), D5.1 (VSS), D6.1 (VSS), D7.1 (VSS), D8.1 (VSS), D9.1 (VSS), D10.1 (VSS), D11.1 (VSS), D12.1 (VSS), D13.1 (VSS), D14.1 (VSS), D15.1 (VSS), D16.1 (VSS), D17.1 (VSS), D18.1 (VSS), D19.1 (VSS), D20.1 (VSS), D21.1 (VSS), D22.1 (VSS), D23.1 (VSS), D24.1 (VSS), D25.1 (VSS), D26.1 (VSS), D27.1 (VSS), D28.1 (VSS), D29.1 (VSS), D30.1 (VSS), D31.1 (VSS), D32.1 (VSS), D33.1 (VSS), D34.1 (VSS), D35.1 (VSS), D36.1 (VSS), D37.1 (VSS), D38.1 (VSS), D39.1 (VSS), D40.1 (VSS), D41.1 (VSS), J1.2, J1.3, J2.1, J2.2
unnamed: D1.4 (DOUT), D2.2 (DIN)
unnamed: D2.4 (DOUT), D25.2 (DIN)
unnamed: D3.4 (DOUT), D4.2 (DIN)
unnamed: D4.4 (DOUT), D5.2 (DIN)
unnamed: D5.4 (DOUT), D6.2 (DIN)
unnamed: D6.4 (DOUT), D7.2 (DIN)
unnamed: D7.4 (DOUT), D8.2 (DIN)
unnamed: D8.4 (DOUT), D9.2 (DIN)
unnamed: D9.4 (DOUT), D10.2 (DIN)
unnamed: D10.4 (DOUT), D11.2 (DIN)
unnamed: D11.4 (DOUT), D12.2 (DIN)
unnamed: D12.4 (DOUT), D13.2 (DIN)
unnamed: D13.4 (DOUT), D14.2 (DIN)
unnamed: D14.4 (DOUT), D15.2 (DIN)
unnamed: D15.4 (DOUT), D16.2 (DIN)
unnamed: D16.4 (DOUT), D17.2 (DIN)
unnamed: D17.4 (DOUT), D18.2 (DIN)
unnamed: D18.4 (DOUT), D19.2 (DIN)
unnamed: D19.4 (DOUT), D20.2 (DIN)
unnamed: D20.4 (DOUT), D21.2 (DIN)
unnamed: D21.4 (DOUT), D22.2 (DIN)
unnamed: D22.4 (DOUT), D23.2 (DIN)
unnamed: D23.4 (DOUT), D24.2 (DIN)
unnamed: D24.4 (DOUT), D26.2 (DIN)
unnamed: D3.2 (DIN), D25.4 (DOUT)
unnamed: D26.4 (DOUT), D27.2 (DIN)
unnamed: D27.4 (DOUT), D28.2 (DIN)
unnamed: D28.4 (DOUT), D29.2 (DIN)
unnamed: D29.4 (DOUT), D30.2 (DIN)
unnamed: D30.4 (DOUT), D31.2 (DIN)
unnamed: D31.4 (DOUT), D32.2 (DIN)
unnamed: D32.4 (DOUT), D33.2 (DIN)
unnamed: D33.4 (DOUT), D34.2 (DIN)
unnamed: D34.4 (DOUT), D35.2 (DIN)
unnamed: D35.4 (DOUT), D36.2 (DIN)
unnamed: D36.4 (DOUT), D37.2 (DIN)
unnamed: D37.4 (DOUT), D38.2 (DIN)
unnamed: D38.4 (DOUT), D39.2 (DIN)
unnamed: D39.4 (DOUT), D40.2 (DIN)
unnamed: D40.4 (DOUT), D41.2 (DIN)
VBUS: C1.1, C2.1, C3.1, C4.1, C5.1, C6.1, C7.1, C8.1, C9.1, C10.1, C11.1, C12.1, C13.1, C14.1, C15.1, C16.1, C17.1, C18.1, C19.1, C20.1, C21.1, C22.1, C23.1, C24.1, C25.1, C26.1, C27.1, C28.1, C29.1, C30.1, C31.1, C32.1, C33.1, C34.1, C35.1, C36.1, C37.1, C38.1, C39.1, C40.1, C41.1, D1.3 (VDD), D2.3 (VDD), D3.3 (VDD), D4.3 (VDD), D5.3 (VDD), D6.3 (VDD), D7.3 (VDD), D8.3 (VDD), D9.3 (VDD), D10.3 (VDD), D11.3 (VDD), D12.3 (VDD), D13.3 (VDD), D14.3 (VDD), D15.3 (VDD), D16.3 (VDD), D17.3 (VDD), D18.3 (VDD), D19.3 (VDD), D20.3 (VDD), D21.3 (VDD), D22.3 (VDD), D23.3 (VDD), D24.3 (VDD), D25.3 (VDD), D26.3 (VDD), D27.3 (VDD), D28.3 (VDD), D29.3 (VDD), D30.3 (VDD), D31.3 (VDD), D32.3 (VDD), D33.3 (VDD), D34.3 (VDD), D35.3 (VDD), D36.3 (VDD), D37.3 (VDD), D38.3 (VDD), D39.3 (VDD), D40.3 (VDD), D41.3 (VDD), J1.4, J1.5

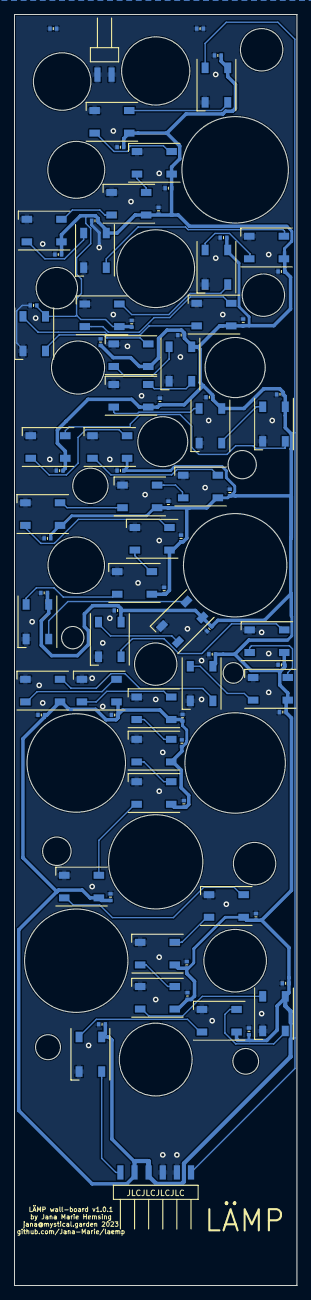
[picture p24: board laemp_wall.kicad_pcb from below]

Board: 2 copper layers, 40.0 x 180.0 mm, 86 parts (86 on the bottom side), 44 nets.

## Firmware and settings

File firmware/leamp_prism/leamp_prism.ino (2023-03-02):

#include <Adafruit_NeoPixel.h>

#define minf(a,b) (((a)<(b))?(a):(b))
#define maxf(a,b) (((a)>(b))?(a):(b))

#define PIN 2
Adafruit_NeoPixel strip = Adafruit_NeoPixel(291, PIN, NEO_GRB + NEO_KHZ800); //(1+44+(41*6))

#define R_IN 33
#define G_IN 34
#define B_IN 35

int16_t adc_color[3] = {0, 0, 0};
uint8_t hue_color[3] = {0, 0, 0};

uint16_t wakeup = false;

uint8_t ledMode = 0;
uint8_t modes = 3;

uint8_t ledHigh;
uint8_t ledLow;
uint16_t ledHighLowTim = 0;
uint16_t ledHighLowTimMax = 3000;
uint8_t modeCounter;

uint32_t firstPixelHue;

byte neopix_gamma[] = {
  0,  0,  0,  0,  0,  0,  0,  0,  0,  0,  0,  0,  0,  0,  0,  0,
  0,  0,  0,  0,  0,  0,  0,  0,  0,  0,  0,  0,  1,  1,  1,  1,
  1,  1,  1,  1,  1,  1,  1,  1,  1,  2,  2,  2,  2,  2,  2,  2,
  2,  3,  3,  3,  3,  3,  3,  3,  4,  4,  4,  4,  4,  5,  5,  5,
  5,  6,  6,  6,  6,  7,  7,  7,  7,  8,  8,  8,  9,  9,  9, 10,
  10, 10, 11, 11, 11, 12, 12, 13, 13, 13, 14, 14, 15, 15, 16, 16,
  17, 17, 18, 18, 19, 19, 20, 20, 21, 21, 22, 22, 23, 24, 24, 25,
  25, 26, 27, 27, 28, 29, 29, 30, 31, 32, 32, 33, 34, 35, 35, 36,
  37, 38, 39, 39, 40, 41, 42, 43, 44, 45, 46, 47, 48, 49, 50, 50,
  51, 52, 54, 55, 56, 57, 58, 59, 60, 61, 62, 63, 64, 66, 67, 68,
  69, 70, 72, 73, 74, 75, 77, 78, 79, 81, 82, 83, 85, 86, 87, 89,
  90, 92, 93, 95, 96, 98, 99, 101, 102, 104, 105, 107, 109, 110, 112, 114,
  115, 117, 119, 120, 122, 124, 126, 127, 129, 131, 133, 135, 137, 138, 140, 142,
  144, 146, 148, 150, 152, 154, 156, 158, 160, 162, 164, 167, 169, 171, 173, 175,
  177, 180, 182, 184, 186, 189, 191, 193, 196, 198, 200, 203, 205, 208, 210, 213,
  215, 218, 220, 223, 225, 228, 231, 233, 236, 239, 241, 244, 247, 249, 252, 255
};

struct rgbywwcw {
  uint8_t r;
  uint8_t g;
  uint8_t b;
  uint8_t y;
  uint8_t ww;
  uint8_t cw;
};

rgbywwcw led;
rgbywwcw led_f;

typedef struct {
  double h;       // angle in degrees
  double s;       // a fraction between 0 and 1
  double v;       // a fraction between 0 and 1
} hsv;

void setup() {
  Serial.begin(115200);
  strip.begin();
  strip.show();
  strip.setBrightness(255);
  delay(500);
}

uint16_t i;

void loop() {
  adc_color[0] = (analogRead(R_IN));
  adc_color[1] = (analogRead(G_IN));
  adc_color[2] = (analogRead(B_IN));

  if (adc_color[0] >= 1500 && adc_color[1] >= 3500 && adc_color[2] >= 3500) {
    ledHigh = 1;
    if (ledLow == 1) {
      if (ledHighLowTim >= millis()) {
        modeCounter++;
      }
      ledLow = 0;
      ledHighLowTim = millis() + ledHighLowTimMax;
    }
  }

  if (adc_color[0] <= 1400 && adc_color[1] >= 3500 && adc_color[2] >= 3500) {
    ledLow = 1;
    if (ledHigh == 1) {
      if (ledHighLowTim >= millis()) {
        modeCounter++;
      }
      ledHigh = 0;
      ledHighLowTim = millis() + ledHighLowTimMax;
    }
  }

  Serial.print(adc_color[0]);
  Serial.print("\t");
  Serial.print(adc_color[1]);
  Serial.print("\t");
  Serial.print(adc_color[2]);
  Serial.print("\t");
  Serial.print(ledHigh);
  Serial.print("\t");
  Serial.print(ledLow);
  Serial.print("\t");
  Serial.print(modeCounter);
  Serial.print("\t");
  Serial.print(millis());
  Serial.print("\t");
  Serial.println(ledHighLowTim);

  if (modeCounter >= 2) {
    strip.setBrightness(255);
    strip.fill(0);

    modeCounter = 0;
    ledMode++;
    if (ledMode >= modes) {
      ledMode = 0;
    }
  }

  if (modeCounter != 0 && ledHighLowTim <= millis()) {
    modeCounter = 0;
  }

  if (adc_color[0] >= 4094 && adc_color[1] >= 4094 && adc_color[2] >= 4094) {
    hue_color[0] = 0;
    hue_color[1] = 0;
    hue_color[2] = 0;
    wakeup = 50;
    setColor(rgbywwcw{0, 0, 0, 0, 0, 0});
    delay(50);
  } else {
    hue_color[0] = map(adc_color[0], 0, 4095, wakeup, 0);
    hue_color[1] = map(adc_color[1], 0, 4095, wakeup, 0);
    hue_color[2] = map(adc_color[2], 0, 4095, wakeup, 0);
    wakeup++;
    if (wakeup > 255) {
      wakeup = 255;
    }
    setColor(_f(rgb_to_rgbw(hsv_to_rgby_naive(rgb2hsv(hue_color[0] / 255.0, hue_color[1] / 255.0, hue_color[2] / 255.0)))));
    delay(1);
  }
  delay(10);
}

hsv test(uint16_t i) {
  hsv _hsv;
  _hsv.s = 1.0;
  _hsv.v = 1.0;
  _hsv.h = i;
  return _hsv;
}

void setColor(rgbywwcw in) {
  uint32_t col = 0;
  uint32_t white = 0;

  // LED 0 BLACK; 41 LED per Panel, 6 Panel; 44 LED for the base

  col = strip.Color(neopix_gamma[in.r], neopix_gamma[in.g], neopix_gamma[in.b]);
  white =  strip.Color(neopix_gamma[in.y], neopix_gamma[in.cw], neopix_gamma[in.ww]);

  if (ledMode == 0) {
    strip.fill(col);

    for (uint16_t i = (41 * 6) + 1; i < strip.numPixels(); i += 2) {
      strip.setPixelColor(i, col);
    }

    for (uint16_t i = (41 * 6) + 2; i < strip.numPixels(); i += 2) {
      strip.setPixelColor(i, white);
    }

  } else if (ledMode == 1) {
    uint8_t nLED = 20;
    float sA = PI * 2 / nLED;
    float piDivFive[nLED] = {0, sA * 1, sA * 2, sA * 3, sA * 4, sA * 5, sA * 6, sA * 7, sA * 8, sA * 9, sA * 10, sA * 11, sA * 12, sA * 13, sA * 14, sA * 15, sA * 16, sA * 17, sA * 18, sA * 19};
    for (uint8_t j = 0; j < nLED; j++) {
      float mult = (sin((millis() / 10000.0) + piDivFive[j]) * (nLED - 1)) - (nLED - 2);
      if (mult <= 0) mult = 0;
      if (mult >= 1) mult = 1;
      uint32_t effectCol = strip.Color(neopix_gamma[in.r] * mult, neopix_gamma[in.g] * mult, neopix_gamma[in.b] * mult);
      for (uint16_t i = 1 + j; i < (41 * 6); i += nLED) {
        strip.setPixelColor(i, effectCol);
      }
    }

    for (uint16_t i = (41 * 6) + 2; i < strip.numPixels(); i += 2) {
      strip.setPixelColor(i, white);
    }

  } else if (ledMode == 2) {
    strip.setBrightness(neopix_gamma[in.ww]);
    firstPixelHue += 64;
    if (firstPixelHue >= 5 * 65536) firstPixelHue = 0;
    strip.rainbow(firstPixelHue);
  }

  strip.setPixelColor(0, (0, 0, 0));
  strip.show();
}

#define FILT_COEF 0.1
rgbywwcw _f(rgbywwcw in) {
  led_f.r = (led_f.r * (1.0 - FILT_COEF)) + (in.r * FILT_COEF);
  led_f.g = (led_f.g * (1.0 - FILT_COEF)) + (in.g * FILT_COEF);
  led_f.b = (led_f.b * (1.0 - FILT_COEF)) + (in.b * FILT_COEF);
  led_f.y = (led_f.y * (1.0 - FILT_COEF)) + (in.y * FILT_COEF);
  led_f.ww = (led_f.ww * (1.0 - FILT_COEF)) + (in.ww * FILT_COEF);
  led_f.cw = (led_f.cw * (1.0 - FILT_COEF)) + (in.cw * FILT_COEF);
  return led_f;
}


rgbywwcw calculateColorTemp(rgbywwcw in) {
  rgbywwcw out = in;
  float temp = (in.b - in.y);
  out.ww = min(uint8_t(min(int(out.ww + temp), 255)), out.ww);
  out.cw = min(uint8_t(min(int(out.cw - temp), 255)), out.cw);
  return out;
}

rgbywwcw rgb_to_rgbywwcw_struct(uint8_t r, uint8_t g, uint8_t b) {
  rgbywwcw out = {r, g, b, 0, 0, 0};
  return out;
}

rgbywwcw rgb_to_rgbw(rgbywwcw in) {
  rgbywwcw out;
  //Get the maximum between R, G, and B
  double tM = max(in.r, max(in.g, in.b));
  uint32_t ret = 0;

  //If the maximum value is 0, immediately return pure black.
  if (tM == 0) {
    out = {0, 0, 0, 0, 0, 0};
    return out;
  }

  //This section serves to figure out what the color with 100% hue is
  double multiplier = 255.0f / tM;
  double hR = in.r * multiplier;
  double hG = in.g * multiplier;
  double hB = in.b * multiplier;

  //This calculates the Whiteness (not strictly speaking Luminance) of the color
  double M = max(hR, max(hG, hB));
  double m = min(hR, min(hG, hB));
  double Luminance = ((M + m) / 2.0f - 127.5f) * (255.0f / 127.5f) / multiplier;

  //Calculate the output values
  int Wo = uint32_t(Luminance);
  int Bo = uint32_t(in.b - Luminance);
  int Ro = uint32_t(in.r - Luminance);
  int Go = uint32_t(in.g - Luminance);

  //Trim them so that they are all between 0 and 255
  if (Wo < 0) Wo = 0;
  if (Bo < 0) Bo = 0;
  if (Ro < 0) Ro = 0;
  if (Go < 0) Go = 0;
  if (Wo > 255) Wo = 255;
  if (Bo > 255) Bo = 255;
  if (Ro > 255) Ro = 255;
  if (Go > 255) Go = 255;

  out.r = Ro;
  out.g = Go;
  out.b = Bo;
  out.y = in.y;
  out.ww = Wo;
  out.cw = Wo / 2;

  return out;
}

hsv rgb2hsv(double r, double g, double b) {
  hsv         out;
  double      min, max, delta;

  min = r < g ? r : g;
  min = min  < b ? min  : b;

  max = r > g ? r : g;
  max = max  > b ? max  : b;

  out.v = max;                                // v
  delta = max - min;
  if (delta < 0.00001)
  {
    out.s = 0;
    out.h = 0; // undefined, maybe nan?
    return out;
  }
  if ( max > 0.0 ) { // NOTE: if Max is == 0, this divide would cause a crash
    out.s = (delta / max);                  // s
  } else {
    // if max is 0, then r = g = b = 0
    // s = 0, h is undefined
    out.s = 0.0;
    out.h = NAN;                            // its now undefined
    return out;
  }
  if ( r >= max )                          // > is bogus, just keeps compilor happy
    out.h = ( g - b ) / delta;        // between yellow & magenta
  else if ( g >= max )
    out.h = 2.0 + ( b - r ) / delta;  // between cyan & yellow
  else
    out.h = 4.0 + ( r - g ) / delta;  // between magenta & cyan

  out.h *= 60.0;                              // degrees

  if ( out.h < 0.0 )
    out.h += 360.0;

  return out;
}

rgbywwcw hsv_to_rgby_naive(hsv hsv) {
  rgbywwcw _tmpmdl;
  memset(&_tmpmdl, 0, sizeof(_tmpmdl));
  return hsv_to_rgby_naive(hsv.h / 360.0, hsv.s, hsv.v, _tmpmdl);
}

rgbywwcw hsv_to_rgby_naive(double h, double s, double v) {
  rgbywwcw _tmpmdl;
  memset(&_tmpmdl, 0, sizeof(_tmpmdl));
  return hsv_to_rgby_naive(h, s, v, _tmpmdl);
}


rgbywwcw hsv_to_rgby_naive(double h, double s, double v, rgbywwcw colorModel) {
  if (s == 0.0) {
    v = v * 255;

    colorModel =  (struct rgbywwcw) {
      v, v, v, v, colorModel.ww, colorModel.cw
    };
  }

  int i = int(h * 8.0);

  double f = (h * 8.0) - i;
  double b = v * (1.0 - s);
  double d = v * (1.0 - s * f);
  double u = v * (1.0 - s * (1.0 - f));
  i = i % 8;

  d = d * 255;
  b = b * 255;
  v = v * 255;
  u = u * 255;

  if (i == 0)colorModel =  (struct rgbywwcw) {
    v, b, b, u, colorModel.ww, colorModel.cw
  };

  if (i == 1)colorModel =  (struct rgbywwcw) {
    d, b, b, v, colorModel.ww, colorModel.cw
  };

  if (i == 2)colorModel =  (struct rgbywwcw) {
    b, u, b, v, colorModel.ww, colorModel.cw
  };

  if (i == 3)colorModel =  (struct rgbywwcw) {
    b, v, b, d, colorModel.ww, colorModel.cw
  };

  if (i == 4)colorModel =  (struct rgbywwcw) {
    b, v, u, b, colorModel.ww, colorModel.cw
  };

  if (i == 5)colorModel =  (struct rgbywwcw) {
    b, d, v, b, colorModel.ww, colorModel.cw
  };

  if (i == 6)colorModel =  (struct rgbywwcw) {
    u, b, v, b, colorModel.ww, colorModel.cw
  };

  if (i == 7)colorModel =  (struct rgbywwcw) {
    v, b, d, b, colorModel.ww, colorModel.cw
  };
  return colorModel;
}

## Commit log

2023-03-02 added 3D files
    [laemp.scad, laemp_base.scad, laemp_base.stl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]
2023-03-02 added base
    [laemp_base.kicad_pcb, laemp_base.kicad_sch]
2023-03-02 added led baord
    [laemp_led_board.kicad_pcb, laemp_led_board.kicad_sch]
2023-03-02 added top
    [laemp_top.kicad_pcb, laemp_top.kicad_sch]
2023-03-02 added walls
    [laemp_wall.kicad_pcb, laemp_wall.kicad_sch, laemp_wall.sch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]
2023-03-02 updated bottom text
    [laemp_base.kicad_pcb]
